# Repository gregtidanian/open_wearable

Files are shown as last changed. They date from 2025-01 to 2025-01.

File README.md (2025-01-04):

A wearable device that is designed for the purpose of testing Daedalus.

The device is designed using the following sub-groups.

**Microcontroller**



The microcontroller is part of the Fanstell BT40 module, containing the Nordic nRF5340 microprocessor.

**Motion Sensor**



The motion sensor is the MPU-6050, which is a 6-axis gyroscope and accelerometer.

**Flash Memory**



The Serial NOR Flash Memory chip is the MX25R6435FM2IL0 component.

**Programming**



Programming and flashing the device is done via the SWD port, designed to mate with a TC2030-NL connector interface.

**RGB LEDs**



The design includes two WS2812 RGB LEDs.

**3.3V Output LDO**



The 3.3V output circuit includes the TPS62740DSSR low-dropout regulator.

**Charging**



The charging circuit includes the MCP73831-2-MC charging chip.

**USB-C**



The USB-C circuit includes the 632723300011 USB-C port.

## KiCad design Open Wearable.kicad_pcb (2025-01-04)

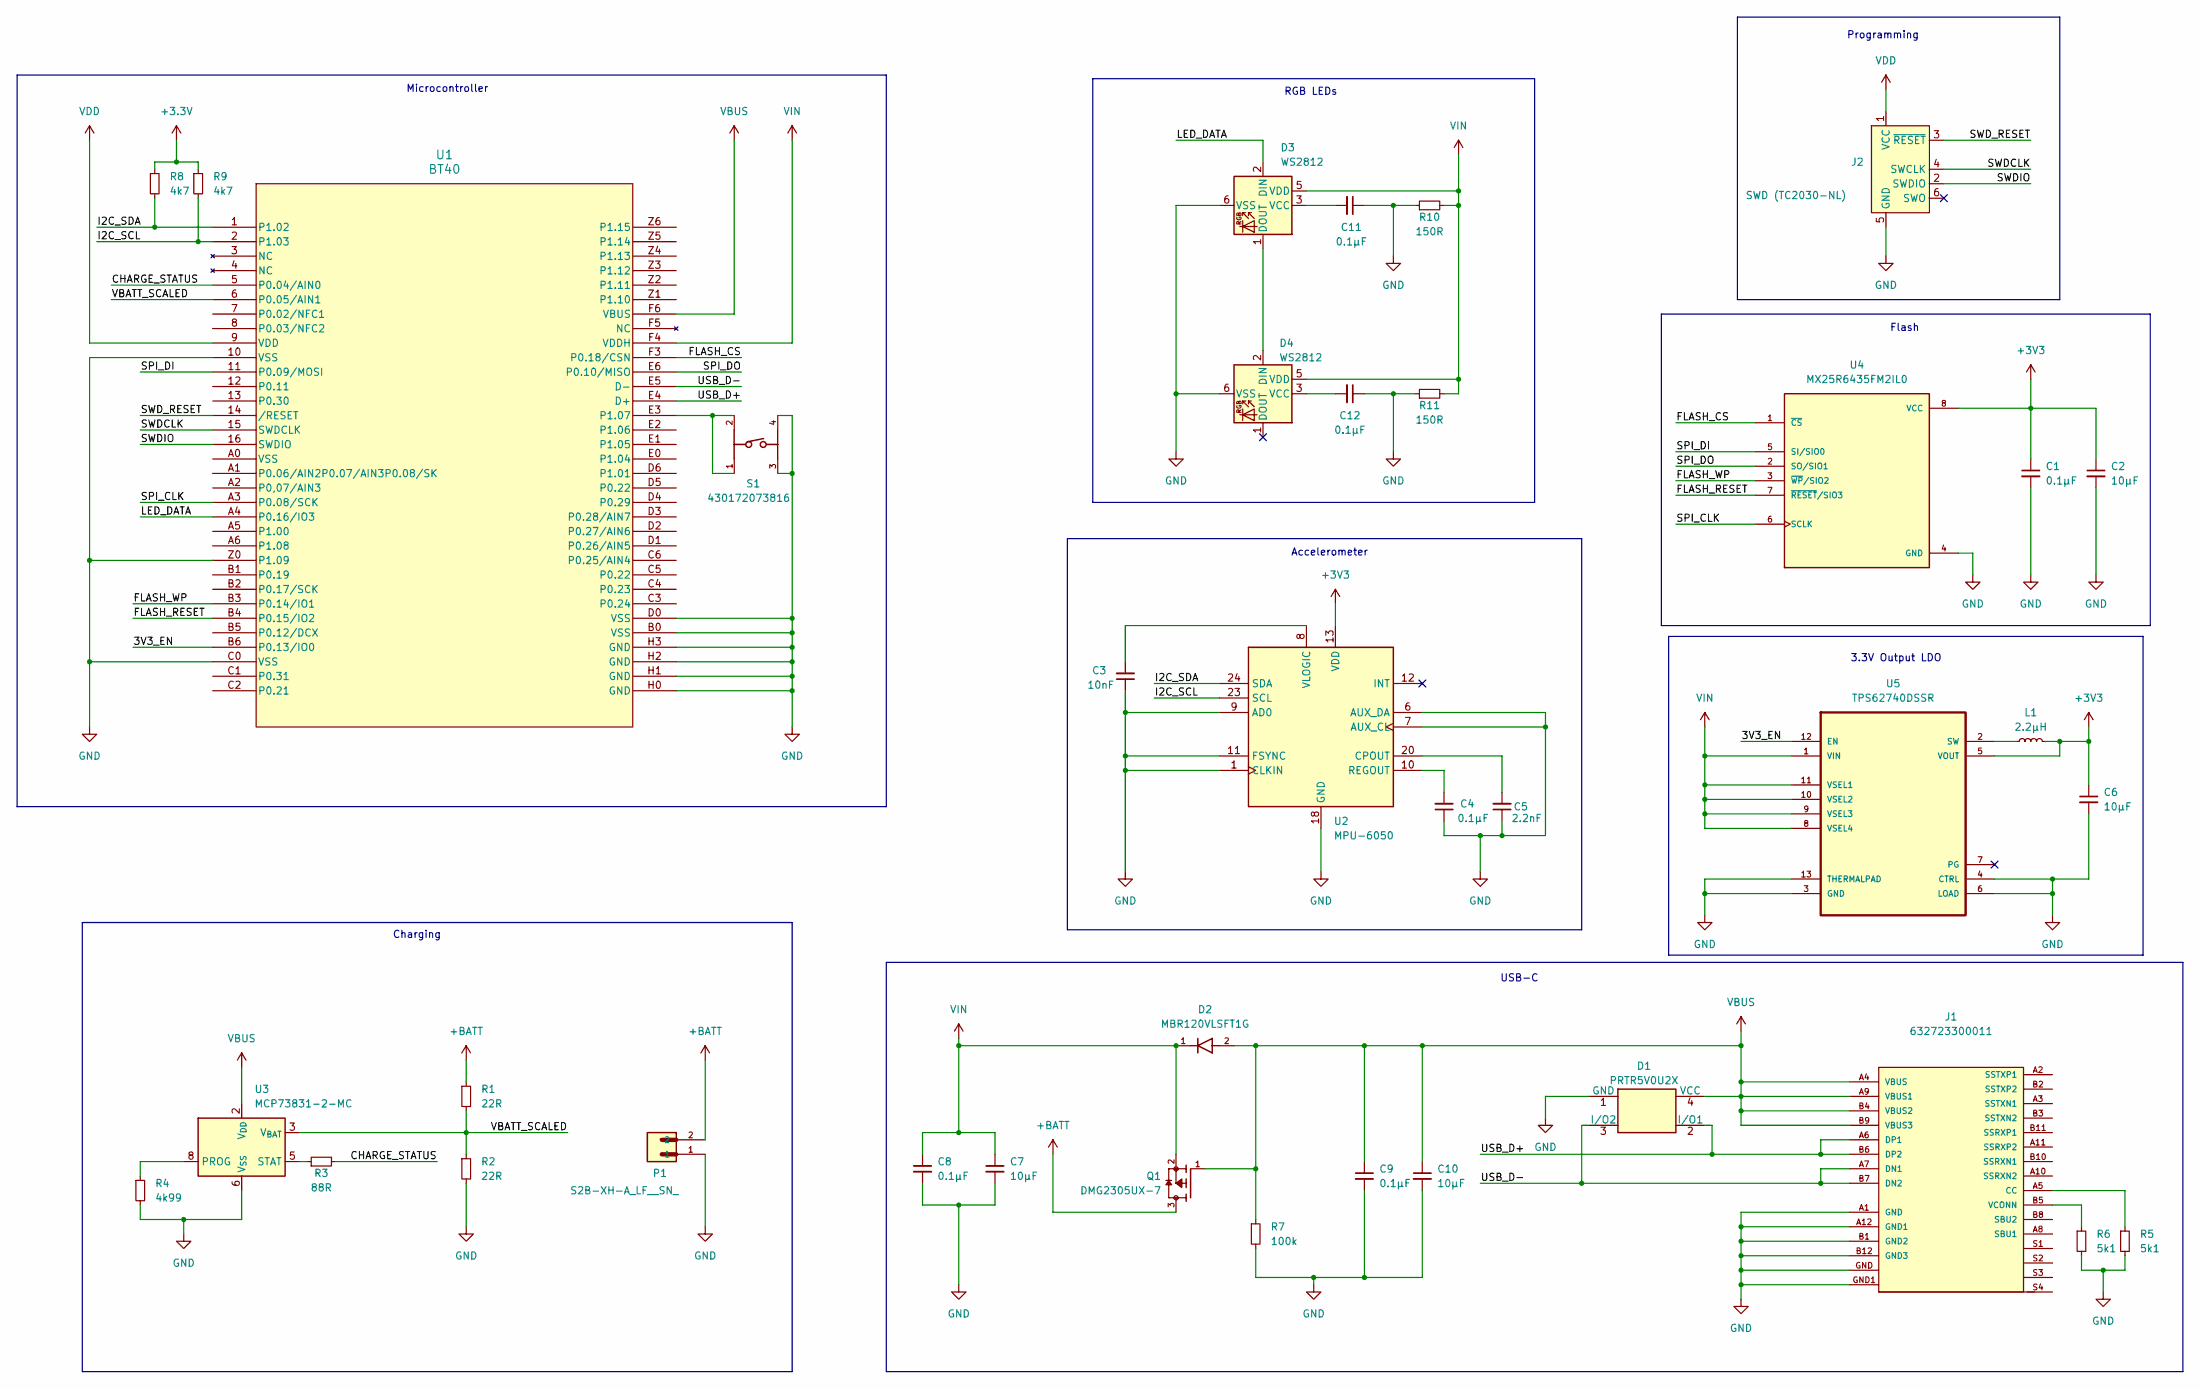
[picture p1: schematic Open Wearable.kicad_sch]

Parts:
C1, C4, C8, C9, C11, C12: 0.1µF; C_0603_1608Metric
C2, C6, C7, C10: 10µF; C_0603_1608Metric
C3: 10nF; C_0603_1608Metric
C5: 2.2nF; C_0603_1608Metric
D1: PRTR5V0U2X; SOT-143
D2: MBR120VLSFT1G; DIOM3616X98N; PARTREV 5/10/2013
D3, D4: WS2812; LED_WS2812_PLCC6_5.0x5.0mm_P1.6mm
J1: 632723300011; PART-NUMBER 632723300011
J2: SWD (TC2030-NL); Tag-Connect_TC2030-IDC-NL_2x03_P1.27mm_Vertical
L1: 2.2µH; L_Coilcraft_LPS3010
P1: S2B-XH-A_LF__SN_; JST_S2B-XH-A_LF__SN_
Q1: DMG2305UX-7; SOT91P240X110-3N_DMG2305UX-7; PARTREV 09/2018
R1, R2: 22R; R_0603_1608Metric
R3: 88R; R_0603_1608Metric
R4: 4k99; R_0603_1608Metric
R5, R6: 5k1; R_0603_1608Metric
R7: 100k; R_0603_1608Metric
R8, R9: 4k7; R_0603_1608Metric
R10, R11: 150R; R_0603_1608Metric
S1: 430172073816; PART-NUMBER 430172073816
U1: BT40; BT40E_FAN_FNL
U2: MPU-6050; InvenSense_QFN-24_4x4mm_P0.5mm
U3: MCP73831-2-MC; DFN-8-1EP_3x2mm_P0.5mm_EP1.7x1.4mm
U4: MX25R6435FM2IL0; SOIC127P790X216-8N; PARTREV 1.6
U5: TPS62740DSSR; SON50P300X200X80-13N

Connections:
+3.3V: R8.1, R9.1
+3V3: C1.1, C2.1, C6.1, L1.2, U2.13 (VDD), U4.8 (VCC), U5.5 (VOUT)
+BATT: P1.2, Q1.3, R1.1
/3V3_EN: U1.B6 (P0.13/IO0), U5.12 (EN)
/CHARGE_STATUS: R3.2, U1.5 (P0.04/AIN0)
/FLASH_CS: U1.F3 (P0.18/CSN), U4.1 (~CS)
/FLASH_RESET: U1.B4 (P0.15/IO2), U4.7 (~RESET/SIO3)
/FLASH_WP: U1.B3 (P0.14/IO1), U4.3 (~WP/SIO2)
/I2C_SCL: R9.2, U1.2 (P1.03), U2.23 (SCL)
/I2C_SDA: R8.2, U1.1 (P1.02), U2.24 (SDA)
/LED_DATA: D3.2 (DIN), U1.A4 (P0.16/IO3)
/SPI_CLK: U1.A3 (P0.08/SCK), U4.6 (SCLK)
/SPI_DI: U1.11 (P0.09/MOSI), U4.5 (SI/SIO0)
/SPI_DO: U1.E6 (P0.10/MISO), U4.2 (SO/SIO1)
/SWDCLK: J2.4 (SWCLK), U1.15 (SWDCLK)
/SWDIO: J2.2 (SWDIO), U1.16 (SWDIO)
/SWD_RESET: J2.3 (~RESET), U1.14 (/RESET)
/USB_D+: D1.2 (I/O1), J1.A6 (DP1), J1.B6 (DP2), U1.E4 (D+)
/USB_D-: D1.3 (I/O2), J1.A7 (DN1), J1.B7 (DN2), U1.E5 (D-)
/VBATT_SCALED: R1.2, R2.1, U1.6 (P0.05/AIN1), U3.3 (V_{BAT}), U3.4 (V_{BAT})
GND: C1.2, C2.2, C3.1, C4.1, C5.1, C6.2, C7.2, C8.2, C9.2, C10.2, C11.1, C12.1, D1.1 (GND), D3.6 (VSS), D4.6 (VSS), J1.A1 (GND), J1.A12 (GND1), J1.B1 (GND2), J1.B12 (GND3), J1.GND, J1.GND1, J2.5 (GND), P1.1, R2.2, R4.2, R5.2, R6.2, R7.2, R10.1, R11.1, S1.3, S1.4, U1.10 (VSS), U1.B0 (VSS), U1.C0 (VSS), U1.D0 (VSS), U1.H0 (GND), U1.H1 (GND), U1.H2 (GND), U1.H3 (GND), U1.Z0 (P1.09), U2.1 (CLKIN), U2.6 (AUX_DA), U2.7 (AUX_CL), U2.9 (AD0), U2.11 (FSYNC), U2.18 (GND), U3.6 (V_{SS}), U4.4 (GND), U5.3 (GND), U5.4 (CTRL), U5.6 (LOAD), U5.13 (THERMALPAD)
unnamed: D3.1 (DOUT), D4.2 (DIN)
unnamed: C11.2, D3.3 (VCC)
unnamed: C12.2, D4.3 (VCC)
unnamed: J1.A5 (CC), R5.1
unnamed: J1.B5 (VCONN), R6.1
unnamed: S1.1, S1.2, U1.E3 (P1.07)
unnamed: C5.2, U2.20 (CPOUT)
unnamed: C4.2, U2.10 (REGOUT)
unnamed: C3.2, U2.8 (VLOGIC)
unnamed: R4.1, U3.8 (PROG)
unnamed: R3.1, U3.5 (STAT)
unnamed: L1.1, U5.2 (SW)
VBUS: C9.1, C10.1, D1.4 (VCC), D2.2, J1.A4 (VBUS), J1.A9 (VBUS1), J1.B4 (VBUS2), J1.B9 (VBUS3), Q1.1, R7.1, U1.F6 (VBUS), U3.1 (V_{DD}), U3.2 (V_{DD})
VDD: J2.1 (VCC), U1.9 (VDD)
VIN: C7.1, C8.1, D2.1, D3.5 (VDD), D4.5 (VDD), Q1.2, R10.2, R11.2, U1.F4 (VDDH), U5.1 (VIN), U5.8 (VSEL4), U5.9 (VSEL3), U5.10 (VSEL2), U5.11 (VSEL1)

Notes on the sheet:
RGB LEDs
Charging
Accelerometer
Programming
USB-C
Flash
Microcontroller
3.3V Output LDO

Board: 2 copper layers, 38 parts (0 on the bottom side), 36 nets, no tracks yet.
